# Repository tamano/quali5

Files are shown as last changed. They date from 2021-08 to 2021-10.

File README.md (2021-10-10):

# Quali5
Quali5は、シンプルな左手用マクロパッドです。
親指キーでレイヤー切り替え可能な4個のキーで、合計8個のキーとして使う事が出来ます。
(QMK Firmwareを書き換えることでキーアサインは自由に変更可能です)

Quali5 is a simple left-handed macropad.
It can be used as an 8-key keybaord with 2 layered 4 keys which can toggle with a thumb key.
(You can change key assigns with QMK Firmware)

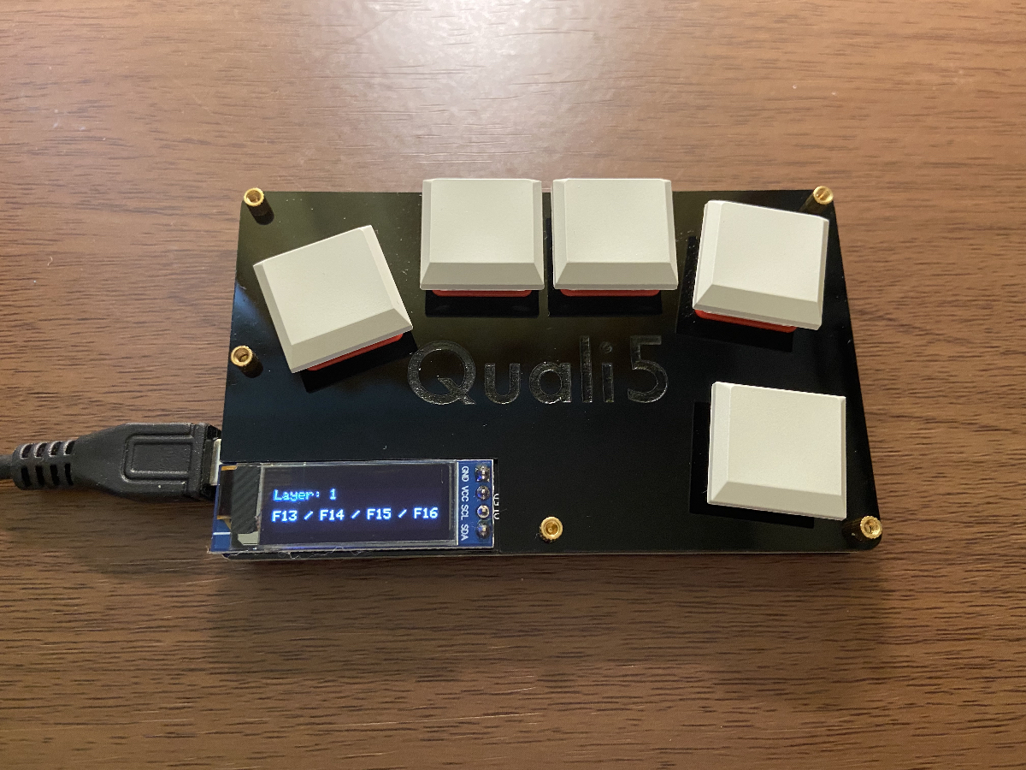
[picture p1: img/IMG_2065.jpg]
quali5-top


## Documents
- [注文方法 / How to Order](doc/how_to_order.md)
- [組み立て方法 / Build Guide](doc/build_guide.md)
- [キーマップのカスタマイズ方法 / How to Change Keymaps](doc/customize_keymap.md)

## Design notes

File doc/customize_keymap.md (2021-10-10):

# キーマップのカスタマイズ方法 / How to Change Keymaps 

キーマップを変更するには、[Remap](https://remap-keys.app/)を使う方法や、[VIA](https://caniusevia.com/)を使う方法があります。

<br>

To change the keymap, you can use [Remap](https://remap-keys.app/) or [VIA](https://caniusevia.com/).

<br>

## Remapを使う方法 / Using Remap

[Remap](https://remap-keys.app/)にアクセスして、 `START REMAP FOR YOUR KEYBOARD` をクリックし、Quali5を選択します。

その後、[こちらのJSONファイル](https://github.com/tamano/qmk_firmware/releases/download/quali5-rev.2a/quali5.json)を読み込みます。

画面からキーマップを変更した後、 `Flash` ボタンで書き込んでください。

詰まった場合は、[こちらのブログ記事](https://salicylic-acid3.hatenablog.com/entry/remap-manual)が非常にわかりやすいので、参考にしてみてください。

<br>

Visit [Remap](https://remap-keys.app/), click `START REMAP FOR YOUR KEYBOARD`, and select Quali5.

Then load the [JSON file here](https://github.com/tamano/qmk_firmware/releases/download/quali5-rev.2a/quali5.json).

After changing the keymap on the screen, use the `Flash` button to write it.

<br>

## VIAを使う方法 / Using VIA

VIAを起動して、左上の File メニューより `Import Keymap` を選択し、[こちらのJSONファイル](https://github.com/tamano/qmk_firmware/releases/download/quali5-rev.2a/quali5.json)を読み込んでください。

<br>

Start VIA, select `Import Keymap` from the File menu in the upper left corner, and load [this JSON file](https://github.com/tamano/qmk_firmware/releases/download/quali5-rev.2a/quali5.json).

<br>

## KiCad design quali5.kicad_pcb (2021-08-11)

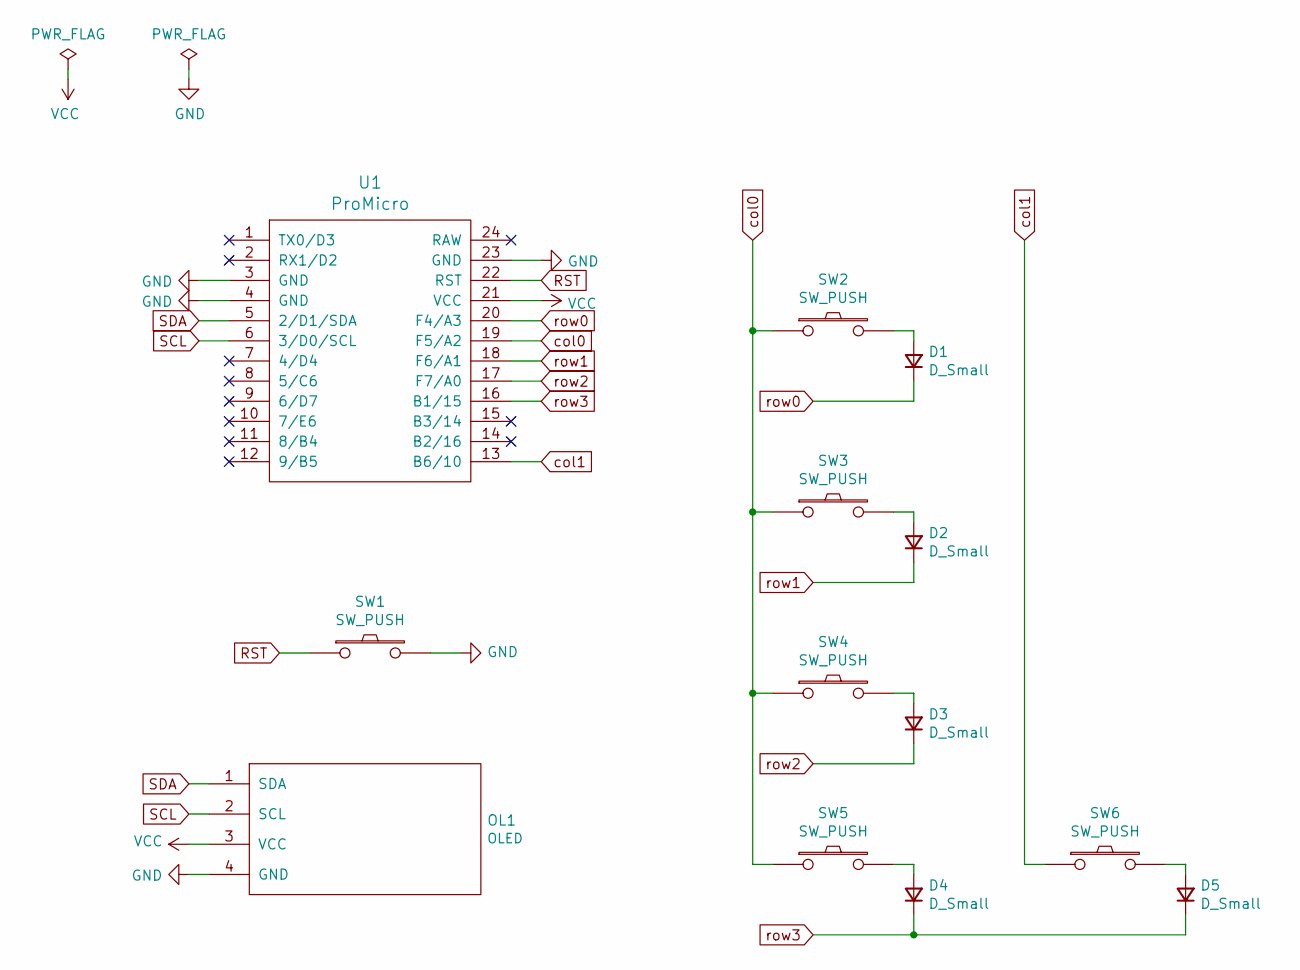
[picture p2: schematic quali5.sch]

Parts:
D1, D2, D3, D4, D5: D_Small; D3_SMD
OL1: OLED
SW1: SW_PUSH; ResetSW_1side
SW2, SW3, SW4, SW5, SW6: SW_PUSH; ChocV1_V2_Hotswap
U1: ProMicro; ProMicro_v3.5

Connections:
GND: OL1.4 (GND), SW1.2, U1.3 (GND), U1.4 (GND), U1.23 (GND)
unnamed: D1.2 (A), SW2.2
unnamed: D2.2 (A), SW3.2
unnamed: D3.2 (A), SW4.2
unnamed: D4.2 (A), SW5.2
unnamed: D5.2 (A), SW6.2
RST: SW1.1, U1.22 (RST)
SCL: OL1.2 (SCL), U1.6 (3/D0/SCL)
SDA: OL1.1 (SDA), U1.5 (2/D1/SDA)
VCC: OL1.3 (VCC), U1.21 (VCC)
col0: SW2.1, SW3.1, SW4.1, SW5.1, U1.19 (F5/A2)
col1: SW6.1, U1.13 (B6/10)
row0: D1.1 (K), U1.20 (F4/A3)
row1: D2.1 (K), U1.18 (F6/A1)
row2: D3.1 (K), U1.17 (F7/A0)
row3: D4.1 (K), D5.1 (K), U1.16 (B1/15)

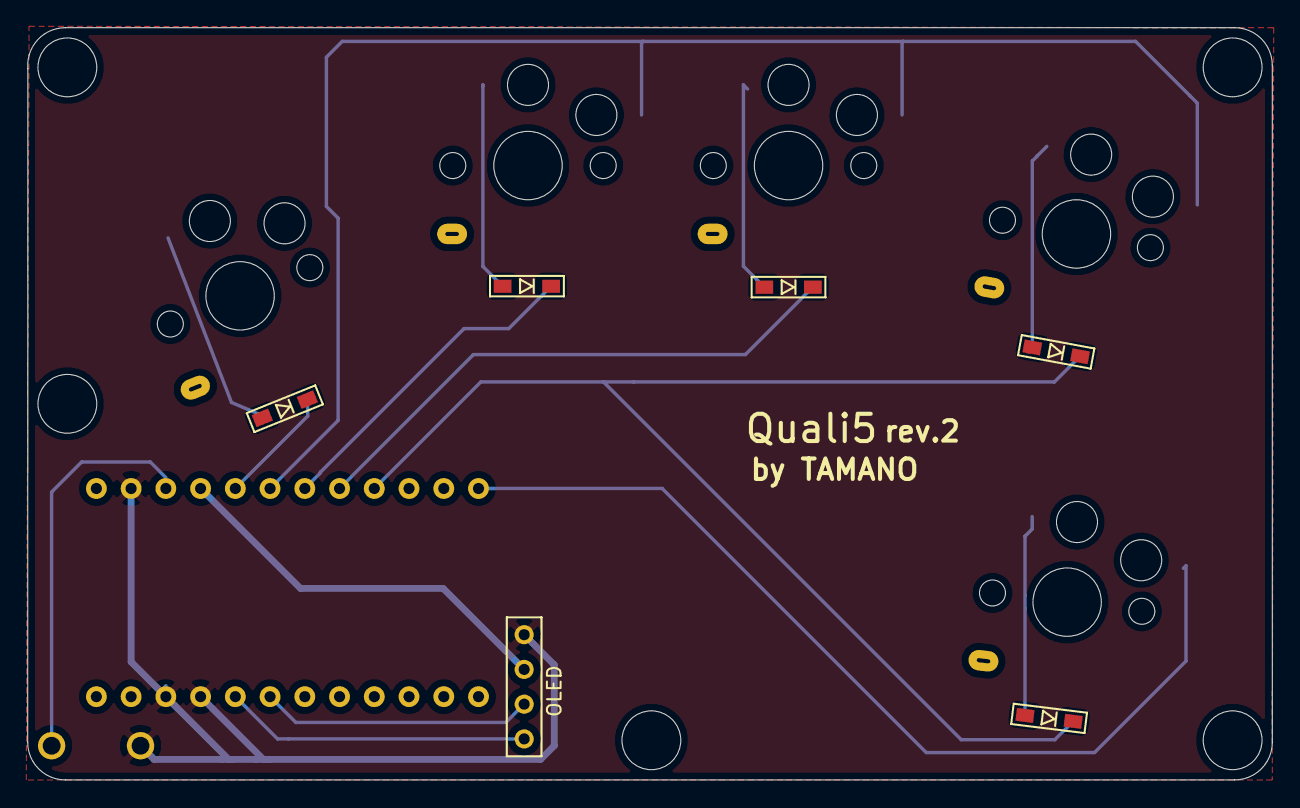
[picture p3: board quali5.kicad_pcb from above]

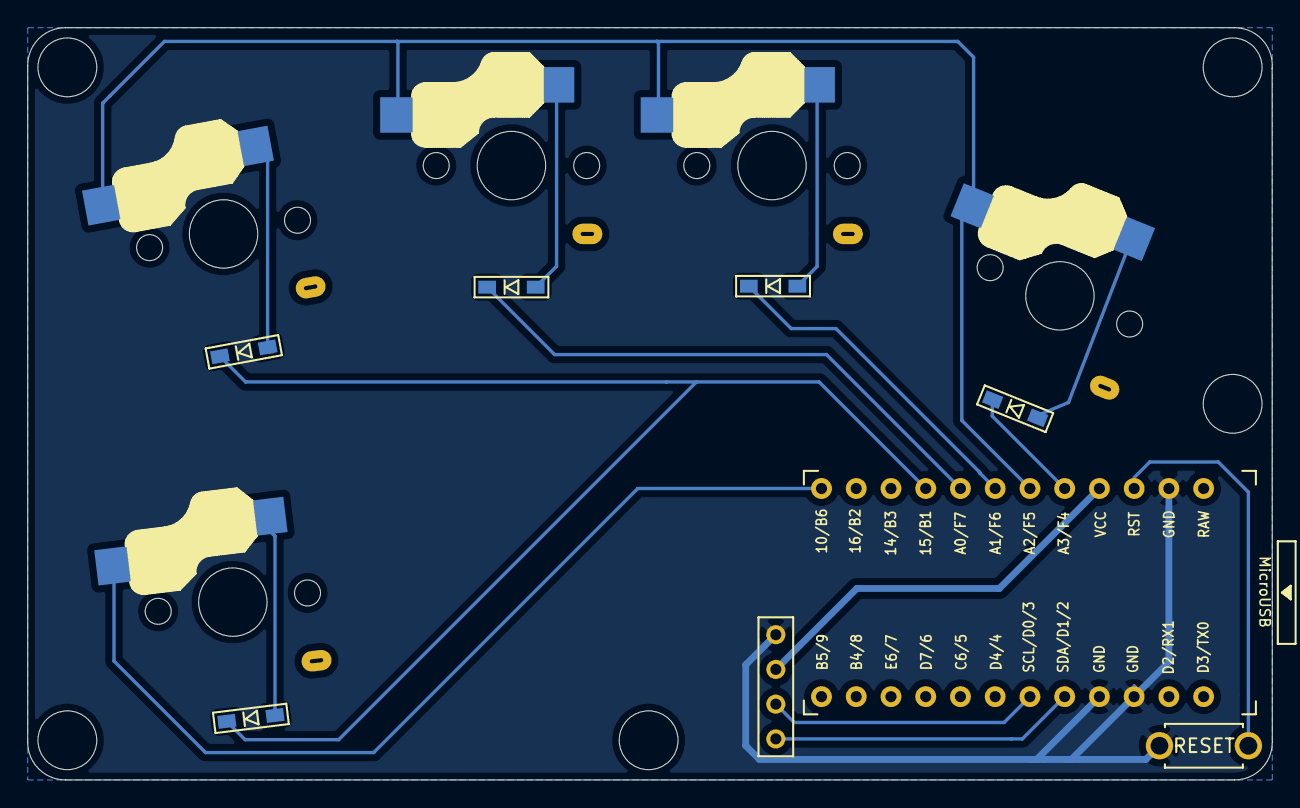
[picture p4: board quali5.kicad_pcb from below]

Board: 2 copper layers, 91.0 x 55.0 mm, 18 parts (7 on the bottom side), 16 nets.

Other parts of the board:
Ref**: Val**; M2_HOLE_v2
Ref**#2, Ref**#3, Ref**#4, Ref**#5: Val**; M2_HOLE_v2

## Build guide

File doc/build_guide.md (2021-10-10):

# ビルドガイド / Build Guide

* [材料 / Parts](#%E6%9D%90%E6%96%99--parts)
* [組み立て手順](#%E7%B5%84%E3%81%BF%E7%AB%8B%E3%81%A6%E6%89%8B%E9%A0%86)
    * [1. ダイオードをハンダ付けする / Solder diodes](#1-%E3%83%80%E3%82%A4%E3%82%AA%E3%83%BC%E3%83%89%E3%82%92%E3%83%8F%E3%83%B3%E3%83%80%E4%BB%98%E3%81%91%E3%81%99%E3%82%8B--solder-diodes)
    * [2. スイッチ用PCBソケットをハンダ付けする / Solder PCB Hot-swappable sockets](#2-%E3%82%B9%E3%82%A4%E3%83%83%E3%83%81%E7%94%A8pcb%E3%82%BD%E3%82%B1%E3%83%83%E3%83%88%E3%82%92%E3%83%8F%E3%83%B3%E3%83%80%E4%BB%98%E3%81%91%E3%81%99%E3%82%8B--solder-pcb-hot-swappable-sockets)
    * [3. ピンヘッダをハンダ付けする / Solder pin headers to PCB plate](#3-%E3%83%94%E3%83%B3%E3%83%98%E3%83%83%E3%83%80%E3%82%92%E3%83%8F%E3%83%B3%E3%83%80%E4%BB%98%E3%81%91%E3%81%99%E3%82%8B--solder-pin-headers-to-pcb-plate)
    * [4. ProMicroをハンダ付けする / Solder the ProMicro](#4-promicro%E3%82%92%E3%83%8F%E3%83%B3%E3%83%80%E4%BB%98%E3%81%91%E3%81%99%E3%82%8B--solder-the-promicro)
    * [5. リセットスイッチをハンダ付けする / Solder a reset switch](#5-%E3%83%AA%E3%82%BB%E3%83%83%E3%83%88%E3%82%B9%E3%82%A4%E3%83%83%E3%83%81%E3%82%92%E3%83%8F%E3%83%B3%E3%83%80%E4%BB%98%E3%81%91%E3%81%99%E3%82%8B--solder-a-reset-switch)
    * [6. OLEDにピンヘッダをハンダ付けする / Solder a pin header to an OLED](#6-oled%E3%81%AB%E3%83%94%E3%83%B3%E3%83%98%E3%83%83%E3%83%80%E3%82%92%E3%83%8F%E3%83%B3%E3%83%80%E4%BB%98%E3%81%91%E3%81%99%E3%82%8B--solder-a-pin-header-to-an-oled)
    * [7. OLEDをハンダ付けする / Solder the OLED to the the PCB plate](#7-oled%E3%82%92%E3%83%8F%E3%83%B3%E3%83%80%E4%BB%98%E3%81%91%E3%81%99%E3%82%8B--solder-the-oled-to-the-the-pcb-plate)
    * [8. スイッチとキーキャップをトッププレートにはめる / Attach switchs and keycaps to the top plate](#8-%E3%82%B9%E3%82%A4%E3%83%83%E3%83%81%E3%81%A8%E3%82%AD%E3%83%BC%E3%82%AD%E3%83%A3%E3%83%83%E3%83%97%E3%82%92%E3%83%88%E3%83%83%E3%83%97%E3%83%97%E3%83%AC%E3%83%BC%E3%83%88%E3%81%AB%E3%81%AF%E3%82%81%E3%82%8B--attach-switchs-and-keycaps-to-the-top-plate)
    * [9. トッププレートをPCB基板にはめ込む / Mount the top plate over the PCB board](#9-%E3%83%88%E3%83%83%E3%83%97%E3%83%97%E3%83%AC%E3%83%BC%E3%83%88%E3%82%92pcb%E5%9F%BA%E6%9D%BF%E3%81%AB%E3%81%AF%E3%82%81%E8%BE%BC%E3%82%80--mount-the-top-plate-over-the-pcb-board)
    * [10. ボトムプレートにスペーサーをねじ止めする / Attach spacers to the bottom plate with screws](#10-%E3%83%9C%E3%83%88%E3%83%A0%E3%83%97%E3%83%AC%E3%83%BC%E3%83%88%E3%81%AB%E3%82%B9%E3%83%9A%E3%83%BC%E3%82%B5%E3%83%BC%E3%82%92%E3%81%AD%E3%81%98%E6%AD%A2%E3%82%81%E3%81%99%E3%82%8B--attach-spacers-to-the-bottom-plate-with-screws)
    * [11. トッププレートとPCB基板をボトムプレートにはめ込む / Mount the top plate & PCB board over the bottom plate](#11-%E3%83%88%E3%83%83%E3%83%97%E3%83%97%E3%83%AC%E3%83%BC%E3%83%88%E3%81%A8pcb%E5%9F%BA%E6%9D%BF%E3%82%92%E3%83%9C%E3%83%88%E3%83%A0%E3%83%97%E3%83%AC%E3%83%BC%E3%83%88%E3%81%AB%E3%81%AF%E3%82%81%E8%BE%BC%E3%82%80--mount-the-top-plate--pcb-board-over-the-bottom-plate)
    * [12. トッププレートをねじ止めする / Screw the top plate and PCB board to bottom plate](#12-%E3%83%88%E3%83%83%E3%83%97%E3%83%97%E3%83%AC%E3%83%BC%E3%83%88%E3%82%92%E3%81%AD%E3%81%98%E6%AD%A2%E3%82%81%E3%81%99%E3%82%8B--screw-the-top-plate-and-pcb-board-to-bottom-plate)
    * [13. ファームウェアを書き込む / Flash the Firmware](#13-%E3%83%95%E3%82%A1%E3%83%BC%E3%83%A0%E3%82%A6%E3%82%A7%E3%82%A2%E3%82%92%E6%9B%B8%E3%81%8D%E8%BE%BC%E3%82%80--flash-the-firmware)
    * [14. キーマップを変更する / Customizing keymap](https://github.com/tamano/quali5/blob/main/doc/build_guide.md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)

## 材料 / Parts

| 名前 / Name | 個数 / Qty | 備考 / Remarks | 入手方法 / Where to buy |
| -- | -- | -- | -- |
| トッププレート<br>Top plate | 1 | | [注文方法 / How to Order](/doc/how_to_order.md) |
| PCB基板<br>PCB board | 1 | | [注文方法 / How to Order](/doc/how_to_order.md) |
| ボトムプレート<br>Bottom plate | 1 | | [注文方法 / How to Order](/doc/how_to_order.md) |
| ProMicro | 1 | ピンヘッダ付属のもの<br>Choose one includes pin headers | https://shop.yushakobo.jp/products/pro-micro |
| OLED | 1 | ピンヘッダ付属のもの<br>Choose one includes pin headers<br>ピンソケットは不要です<br>Pin Socket is not need | https://shop.yushakobo.jp/products/oled |
| タクタイルスイッチ<br>Tactile switch| 1 | リセットスイッチ用<br>Use as reset switch | https://shop.yushakobo.jp/products/a0800ts-01-1 |
| キーキャップ<br>Keycap | 5 | Kailh Chocロープロファイル互換のもの<br> Choose Kailh Choc V1 compatible one | https://shop.yushakobo.jp/products/pg1350cap-blank |
| キースイッチ<br>Key switch | 5 | Kailh Chocロープロファイル互換のもの<br> Choose Kailh Choc V1 compatible one | https://shop.yushakobo.jp/products/pg1350 |
| スイッチ用PCBソケット<br>PCB Hot-swappable sockets | 5 | Kailh Chocロープロファイル互換のもの<br> Choose Kailh Choc V1 compatible one | https://shop.yushakobo.jp/products/a01ps?variant=37665172553889 |
| 表面実装ダイオード<br>Surface mount diode | 5 | | https://shop.yushakobo.jp/products/a0800di-02-100 |
| M2スリムヘッド小ネジ(5mm)<br>Slim head small screw M2x5 | 5 | ボトムプレート用<br>Use to fix bottom plate | https://shop.yushakobo.jp/products/a0800s2 |
| M2丸型スペーサー(6mm)<br>Round Spacer M2x6 | 5 | | https://shop.yushakobo.jp/products/a0800c2 |
| M2ネジ(3mm)<br>Screw M2x3 | 5 | トッププレート用<br>Use to fix top plate | https://ja.aliexpress.com/item/33022872348.html |

## 組み立て手順
### 1. ダイオードをハンダ付けする / Solder diodes
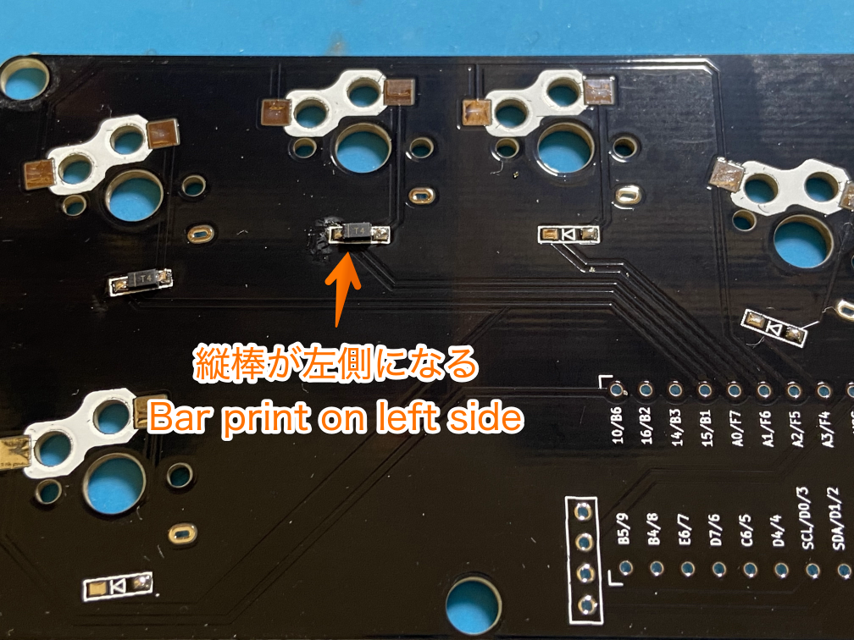
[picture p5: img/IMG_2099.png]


PCBソケットのマークがある面(あるいは、Quali5の名前が書いてない面)にダイオードをハンダ付けします。

その際、ダイオードの向きは、写真のように縦棒のマークが左側に来るように注意してください。

<br>

Solder diodes to the side which have PCB socket marks on it (or the side Quali5 is not printed).

Be careful to orient the diode so that the vertical bar mark is on the left side, as shown in the picture.

<br>

### 2. スイッチ用PCBソケットをハンダ付けする / Solder PCB Hot-swappable sockets
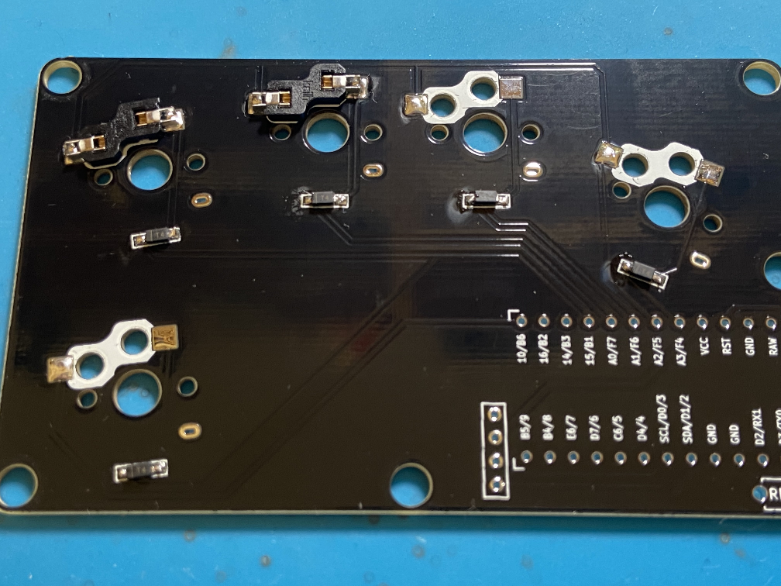
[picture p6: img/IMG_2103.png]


PCBソケットのマークに重なるように、スイッチ用PCBソケットをハンダ付けします。

<br>

Solder the PCB Hot-swappable sockets as the marks instructs.

<br>

### 3. ピンヘッダをハンダ付けする / Solder pin headers to PCB plate
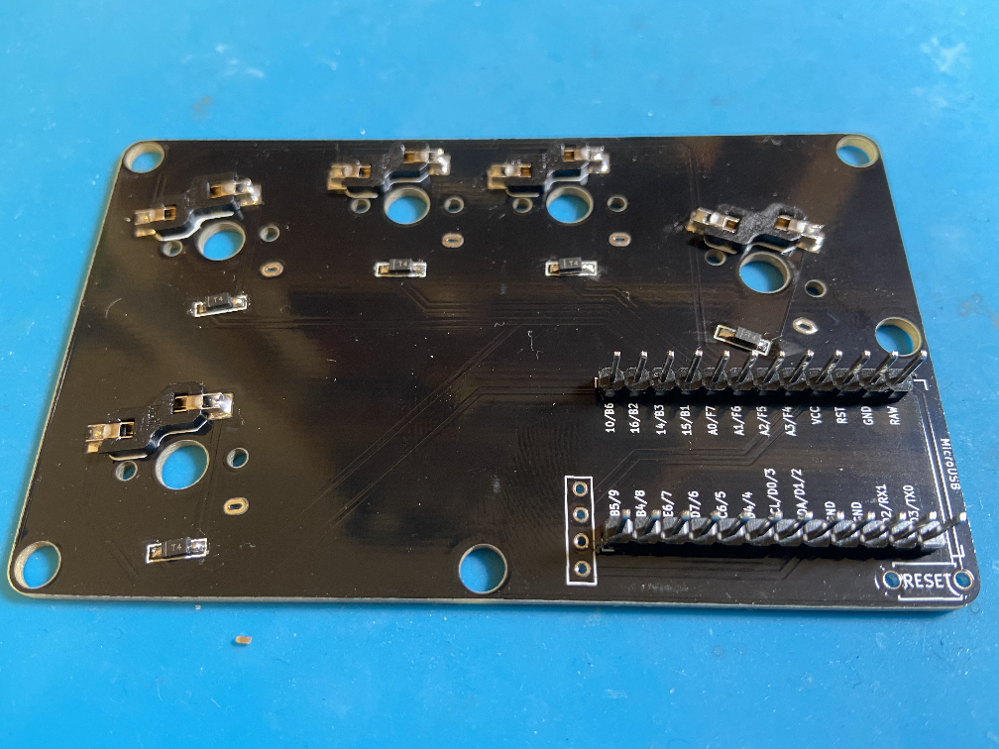
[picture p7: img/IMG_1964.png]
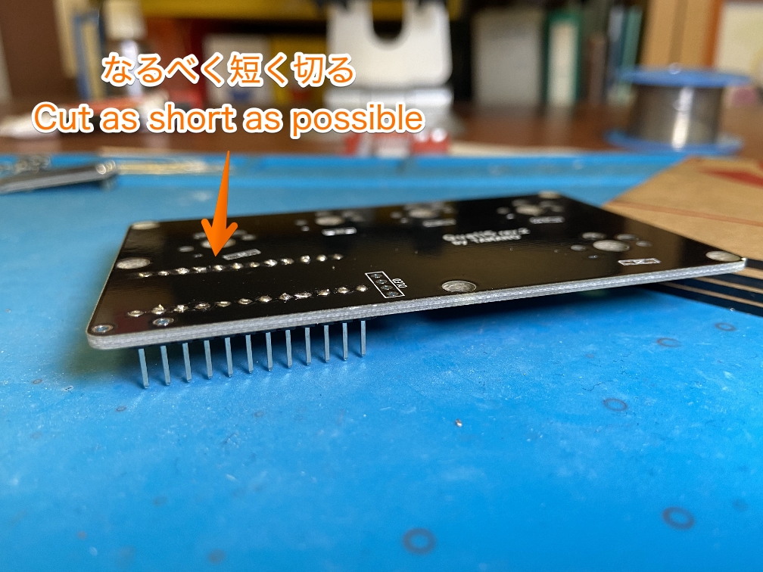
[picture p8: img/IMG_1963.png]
 

ピンヘッダをPCB基板にハンダ付けします。

その後、2枚目の写真のように、裏側の余った足を切り落としてください。ここに出っ張りが残ると、後でトッププレートがPCBから浮いてしまう可能性があります。

<br>

Solder the pin headers to the PCB board.

Then cut off the excess legs on the back side, as shown in the second picture. If there is any protrusion left here, it may cause the top plate does not fit to the PCB board lately.

<br>

### 4. ProMicroをハンダ付けする / Solder the ProMicro
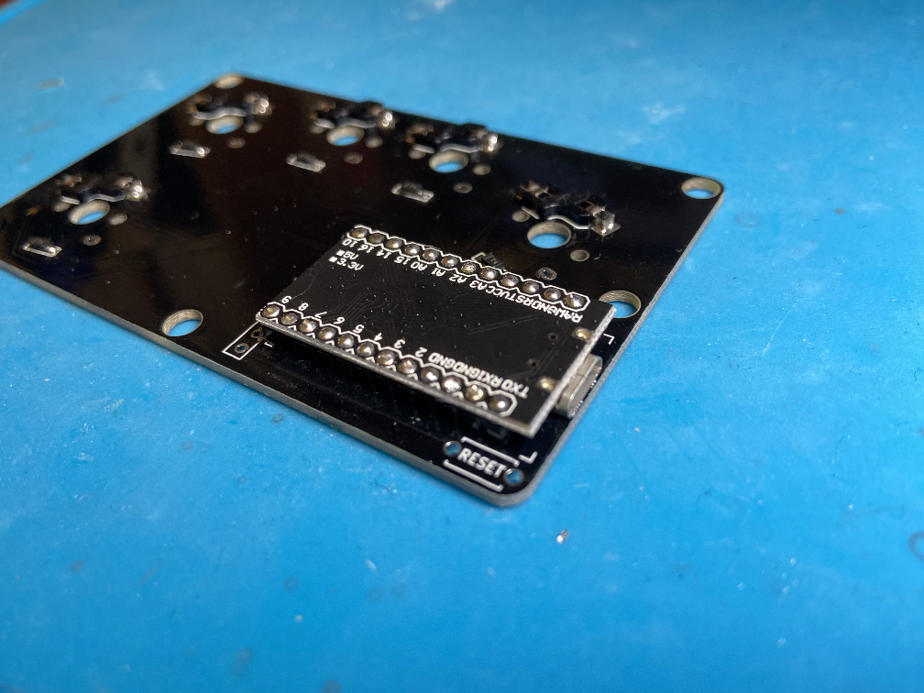
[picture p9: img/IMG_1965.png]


ProMicroをUSB差し込み口が外側になる向きで、PCB基板に半田付けします。

ここでも同様に、ハンダ付けの後で余った足を切り落としてください。

<br>

Solder the ProMicro to the PCB board with the USB port facing outward.

After soldering, cut off the excess legs as we did with pin headers.

<br>

### 5. リセットスイッチをハンダ付けする / Solder a reset switch
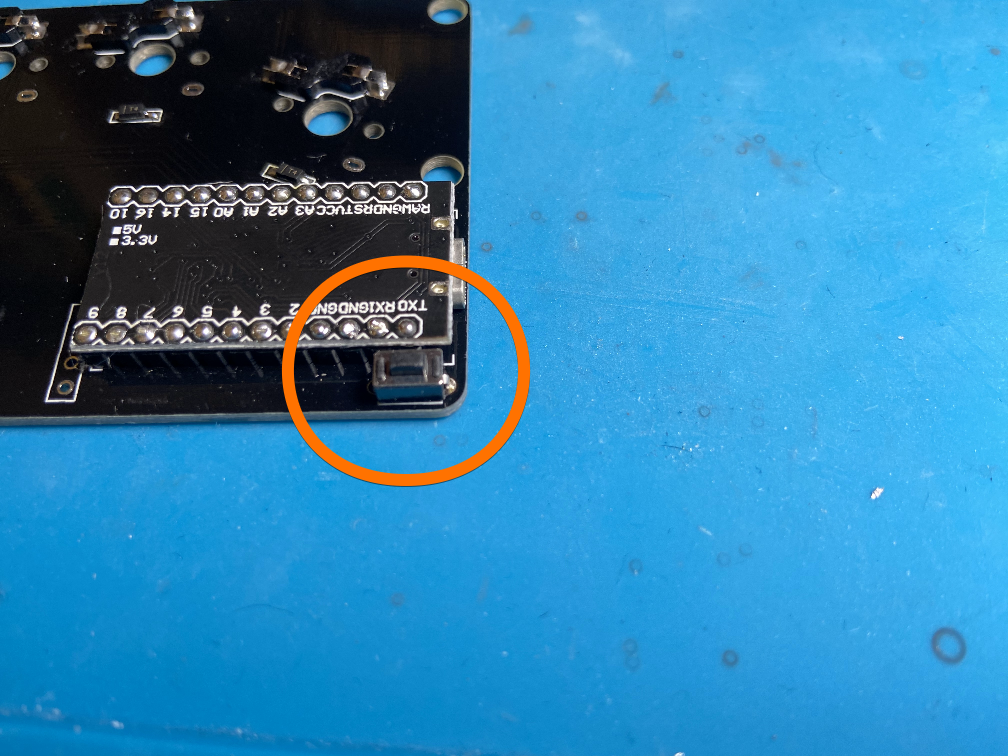
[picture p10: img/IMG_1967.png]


リセットスイッチをPCB基板にハンダ付けします。
<br>

Solder a reset switch to the PCB board.

<br>

### 6. OLEDにピンヘッダをハンダ付けする / Solder a pin header to an OLED
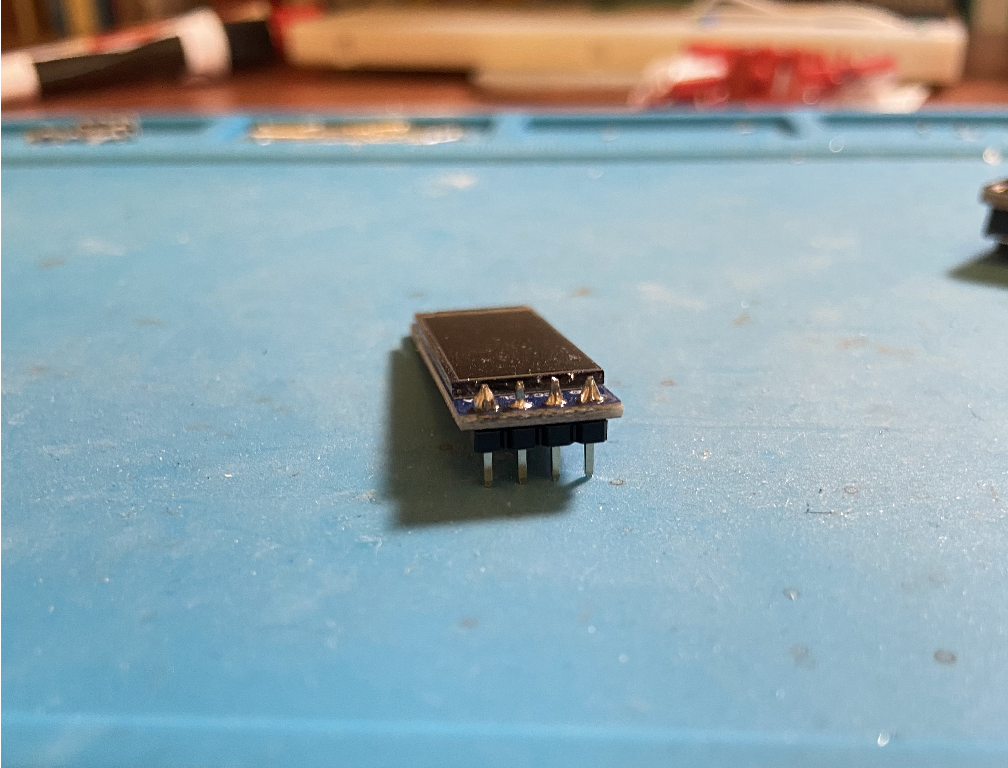
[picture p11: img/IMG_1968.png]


OLEDをPCB基板にハンダ付けする準備として、まずはOLEDに付属のピンヘッダをハンダ付けします。

この時、ピンヘッダの向きに注意してください。ピンヘッダは写真のようにディスプレイと反対側から差し込んだ上で、ディスプレイ側の面をハンダ付けします。

<br>

Solder a pin header that come with OLED to it mountable on PCB board.

Be careful to the direction of the pin header. Confirm that insert it from the opposite side of the display and then solder the display side as shown in the picture.

<br>

### 7. OLEDをハンダ付けする / Solder the OLED to the the PCB plate
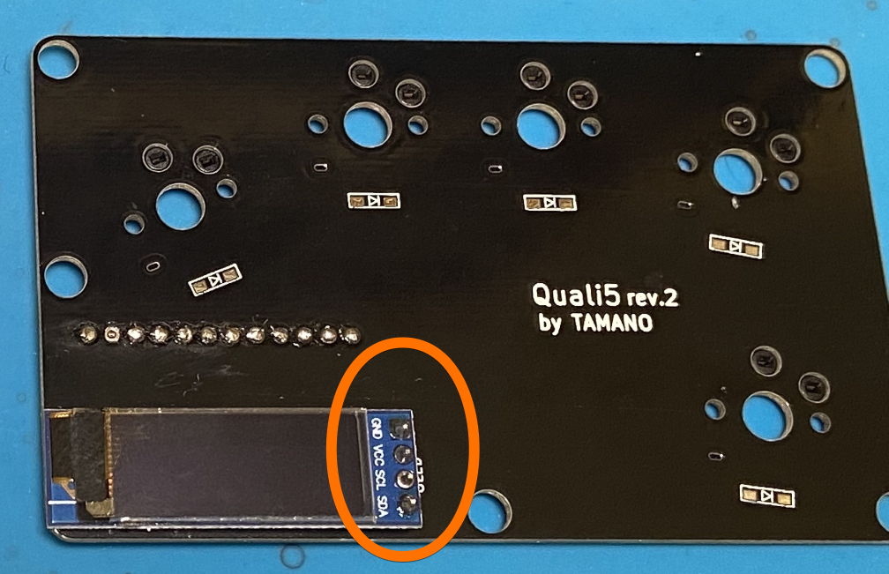
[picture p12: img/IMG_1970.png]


OLEDをPCB基板にハンダ付けします。

<br>

Solder the OLED to the PCB board.

<br>

### 8. スイッチとキーキャップをトッププレートにはめる / Attach switchs and keycaps to the top plate
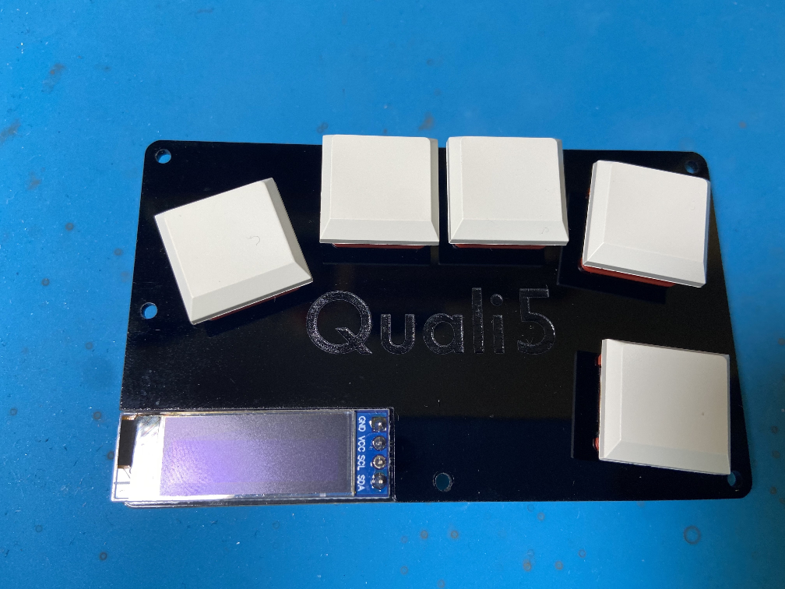
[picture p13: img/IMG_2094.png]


キーキャップをキースイッチにはめた上で、キースイッチをトッププレートにははめます。

この時点では少しぐらつきますが、心配ありません。

<br>

Put the keycaps on the key switchs, and then put them on the top plate.

It may wobble a little at this point, but don't worry.

<br>

### 9. トッププレートをPCB基板にはめ込む / Mount the top plate over the PCB board
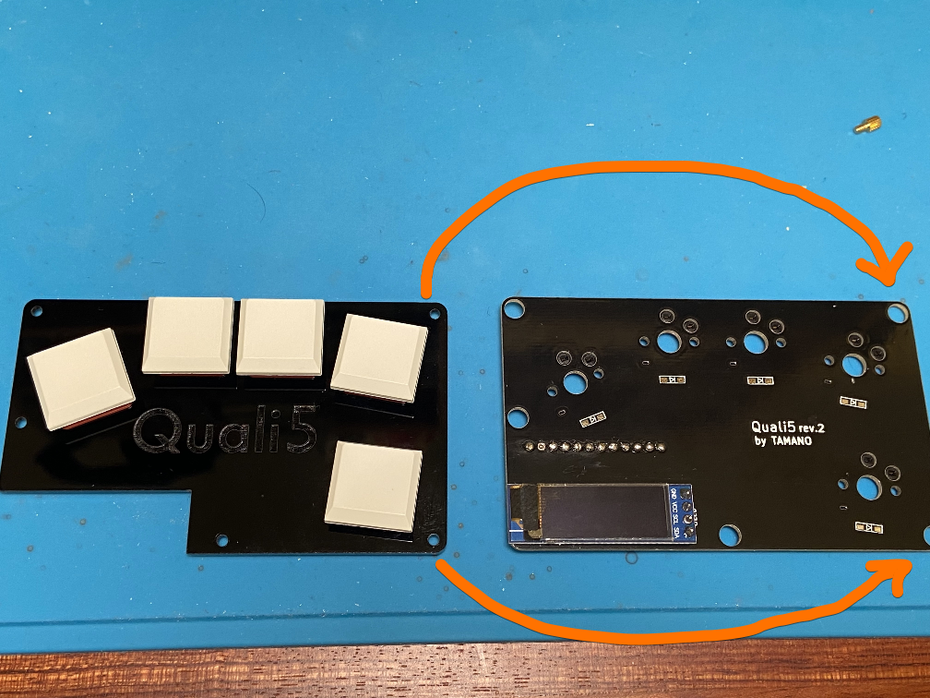
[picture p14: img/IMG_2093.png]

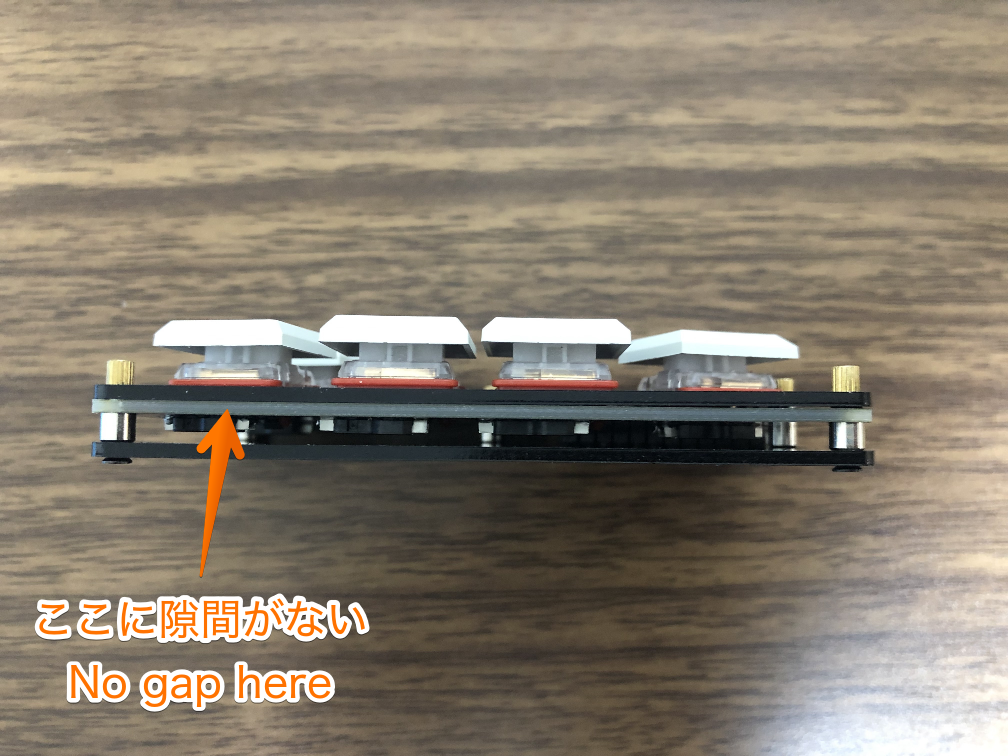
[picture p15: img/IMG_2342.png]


トッププレートのキースイッチの足がPCB基板のソケットの位置と合っている事を確認しながら、トッププレートをPCB基板にはめます。

はめるとスイッチがトッププレートから浮きますが、足の位置が合っていれば、上から抑えるとパチンとはまるはずです。

この時、2枚目の写真のように、トッププレートとPCB基板の間に隙間がない事を確認してください。もし、隙間ができてしまっている場合は、手順3に戻って、足をきっちり切ってください。

<br>

Fit the top plate to the PCB board, making sure that the legs of the key switchs on the top plate are aligned with the sockets on the board.

The switch will lift off the top plate when you insert it, but if the legs are aligned, it should snap into place when you push it in.

After that, make sure that there is no gap between the top plate and the PCB board as shown in the second picture. If there is a gap, please go back to step 3 and cut the legs off tightly.

<br>

### 10. ボトムプレートにスペーサーをねじ止めする / Attach spacers to the bottom plate with screws
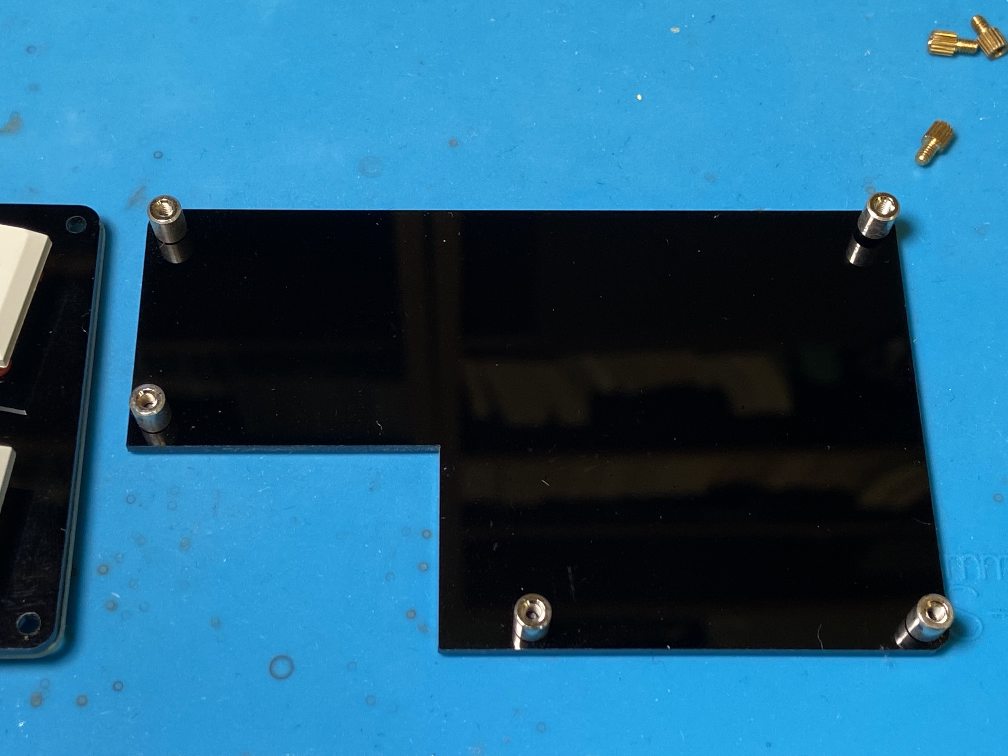
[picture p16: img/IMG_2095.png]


写真の向きにスペーサーをボトムプレートに取り付け、裏側からネジで固定します。

<br>

Attach the spacers to the bottom plate in the orientation shown in the photo, and fix it with screws from the back side.

<br>

### 11. トッププレートとPCB基板をボトムプレートにはめ込む / Mount the top plate & PCB board over the bottom plate
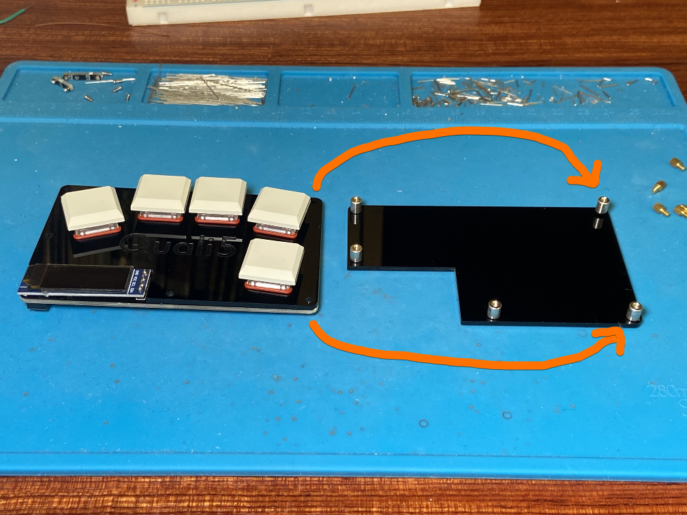
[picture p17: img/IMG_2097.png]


トッププレートとPCB基板を、PCB基板の穴がスペーサーにはまるようにボトムプレートに被せます。

<br>

Mount the top plate and PCB board over the bottom plate with the spacers fit into the holes in the PCB board.

<br>

### 12. トッププレートをねじ止めする / Screw the top plate and PCB board to bottom plate
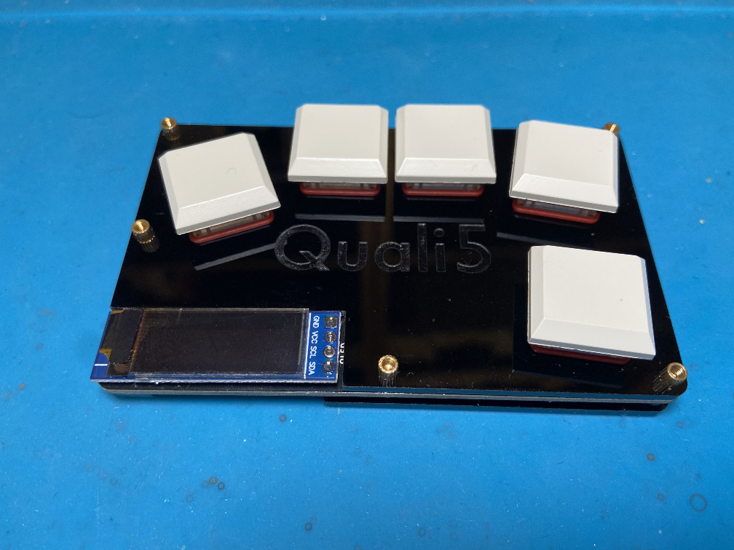
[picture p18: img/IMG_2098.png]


トッププレートの上からねじ止めでボトムプレートを固定して完成です。

<br>

Fix the bottom plate by screwing it on top of the top plate and you are done.

<br>

### 13. ファームウェアを書き込む / Flash the Firmware

完成したキーボードをUSBケーブルでPCに接続した上で、ファームウェアを書き込みます。

ファームウェアの書き込む方法には、[Pro Micro Web Updater](https://sekigon-gonnoc.github.io/promicro-web-updater/index.html)や[QMK Toolbox](https://github.com/qmk/qmk_toolbox)といったツールを使う方法と、QMKコマンドで直接描き込む方法の２種類があるので、いずれかを実施してください。

以下、それぞれについて説明します。

<br>

Connect the completed keyboard to the PC with a USB cable, and write the firmware.

There are 2 ways to write firmware, using a tool such as Pro Micro Web Updater or QMK Toolbox, or directly using QMK commands.

Each way is explained below. So follow one of them.

<br>

#### ツールを使う方法 / Using tool

[Pro Micro Web Updater](https://sekigon-gonnoc.github.io/promicro-web-updater/index.html)や[QMK Toolbox](https://github.com/qmk/qmk_toolbox)を使う事で、簡単にファームウェアを書き込むことができます。

なお、その際のHexファイル(コンパイル済みファームウェア)は、[こちらのファイル](https://github.com/tamano/qmk_firmware/releases/download/quali5-rev.2a/tamano_quali5_via.hex)を利用してください。

Pro Micro Web Updaterの使い方は、[遊舎工房の説明](https://yushakobo.zendesk.com/hc/ja/articles/1500011696701)が丁寧でわかりやすいので参考にしてみてください。

<br>

By using [Pro Micro Web Updater](https://sekigon-gonnoc.github.io/promicro-web-updater/index.html) or [QMK Toolbox](https://github.com/qmk/qmk_toolbox), you can easily write the firmware.

Please use [this file](https://github.com/tamano/qmk_firmware/releases/download/quali5-rev.2a/tamano_quali5_via.hex) as the Hex file (compiled firmware).

<br>

#### QMKコマンドを使う方法 / Using QMK command

以下のコマンドを実行してファームウェアを書き込みます。

まだQMKをインストールしていない場合は、[こちらの手順](https://docs.qmk.fm/#/ja/newbs_getting_started)に従って `2. ビルド環境を準備する` まで実施して環境を整えた上で、以下のコマンドを実施してください)

<br>

Execute the following commands to write the firmware.

If you have not installed QMK yet, please follow [this procedure](https://docs.qmk.fm/#/newbs_getting_started) to `2. Prepare Your Build Environment`, and then execute the following command)

<br>

```bash
cd your_workspace_directory
qmk setup tamano/qmk_firmware --branch quali5
cd qmk_firmware
qmk flash -kb tamano/quali5 -km via          # 画面で指示されたらリセットボタンを押す / Push the reset button when instructed
```

<br>

### 14. キーマップを変更する / Customizing keymap

ファームウェアを書き込んだ後、キーマップを変更する方法については[キーマップのカスタマイズ方法 / How to Change Key Maps](/doc/customize_keymap.md)を参照してください。

<br>

For information about changing keymap after writing the firmware, please refer to [How to Change Keymaps](/doc/customize_keymap.md).

<br>

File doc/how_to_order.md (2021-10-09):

# 注文方法 / How to Order

ここでは、Quali5を[Elecrow](https://www.elecrow.com/)で注文する方法を説明します。

<br>

This page explains how to order Quali5 on [Elecrow](https://www.elecrow.com/) .

<br>

## 基盤の注文 / Order PCB plate

[Elecrow PCB Manufacturing](https://www.elecrow.com/pcb-manufacturing.html)から申し込みます。

それぞれの項目は、以下の表の通り、指定してください（記載がないものは任意です）。

<br>

Apply from [Elecrow PCB Manufacturing](https://www.elecrow.com/pcb-manufacturing.html).

Each item should be specified as in the table below (items not listed are optional).

<br>

| Name | Value |
| ---- | ----- |
| Gerber | [Zip File](https://github.com/tamano/quali5/releases/download/quali5-rev.2/quali5-gerber-pcb.zip) |
| Layer | 2 |
| Dimensions | 91mm x 55mm |
| PCB Thickness | 1.6mm |

<br>

## トッププレートとボトムプレートの注文 / Order Top and Bottom plate

[Acrylic Laser Cutting](https://www.elecrow.com/acrylic-cutting.html)から申し込みます。

それぞれの項目は、以下の表の通り、指定してください（記載がないものは任意です）。

<br>

Apply from [Acrylic Laser Cutting](https://www.elecrow.com/acrylic-cutting.html).

Each item should be specified as in the table below (items not listed are optional).

<br>

| Name | Value |
| ---- | ----- |
| Size | Acrylic 20cm X 20cm Max(Thickness: 2.0mm) |
| File | [Zip File](https://github.com/tamano/quali5/releases/download/quali5-rev.2/quali5-eps-plates.zip) |

<br>

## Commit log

2021-05-23 Initialize project with KiCad
    [quali5.kicad_pcb, quali5.sch]
2021-05-23 Create circuit diagram.
    [quali5.sch]
2021-05-28 Designed PCB footprint
    [quali5.kicad_pcb, quali5.sch]
2021-05-28 Create gerber file for PCB.
    [quali5.kicad_pcb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]
2021-05-28 Create plate data
    [quali5.kicad_pcb-bottom-plate.kicad_pcb, quali5.kicad_pcb-top-plate.kicad_pcb]
2021-08-11 Update PCB for rev.2
    [quali5.kicad_pcb, quali5.sch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]
2021-08-11 Create Plates for rev.2
    mv plate
    [quali5-plate-bottom.kicad_pcb, quali5-plate-top.kicad_pcb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]
